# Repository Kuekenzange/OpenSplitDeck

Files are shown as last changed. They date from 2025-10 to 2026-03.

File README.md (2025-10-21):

# OpenSplitDeck (v0.2)

A custom modular wireless controller inspired by the Steam Deck and Steam Controller. Features trackpads, detachable halves, and full HID support. Built from scratch using nRF52840 microcontrollers and the Enhanced ShockBurst protocol. [Video](https://youtu.be/ycMgIToLav8?si=cVztny4IiIS_V4oI) 

Join the [Discord!](https://discord.gg/ZtV34Hwx7y)

> **Note**  
> This project is in an early development stage — v0.2. Expect breaking changes, bugs, and frequent updates.

---

## 🚀 Project Goals

- 🎮 Emulate a Steam Deck-like controller with modular, wireless halves
- 🖱️ Support mouse, keyboard, and gamepad HID modes
- 🧲 Custom-built trackpads using the Azoteq IQS7211E sensor
- 🔋 Magnetic pogo-pin charging and attachment system
- 🛠️ Fully open-source hardware and firmware

---

## 😎 Current Status

- 🎮 Emulates a DS4 Controller - This lets us use steam input for the trackpads. Ideally I want it to show up as a steamdeck controller but that is seeming like a much harder task than I thought.
- 🖱️ Support mouse, keyboard, and gamepad HID modes. - Kinda. Mouse and keyboard are properly setup in the HID desccriptors, I just have not implpemented them yet.
- 🧲 Custom-built trackpads using the Azoteq IQS7211E sensor - Yes.
- 🔋 Magnetic pogo-pin charging and attachment system. - Yes but they only support charging. I would like to find a way to make the 2 halves of the controller communicate with each other.
- 🛠️ Fully open-source hardware and firmware - 😎

Controller is still definetly in the early phases. However it does function and work as expected. There is still a lot to improve, optimize and other features to add. Stay tuned for the progression of this project and feel free to build one yourself! Let me know if my instructions are bad.

---

## ✅ v0.2 Development Checklist

### Hardware
- [x] Left and right controller halves (nRF52840)
- [x] USB dongle (nRF52840)
- [x] Custom trackpad PCBs (IQS7211E)
- [ ] 3D printable version of the Shell
- [x] Controller PCBs(left + right)
- [ ] Joystick PCBs(to drive down cost)
- [ ] gp2040ce + nrf dongle

### Firmware
- [x] ESB-based wireless communication
- [x] Mouse + Gamepad + Keyboard HID reports
- [x] Input parsing for trackpads and buttons
- [x] Haptics
- [ ] Rumble support
- [x] Gyro Support
- [ ] Calibration routines + save to internal memory
- [ ] Configurable modes (gesture/tap/mouse/gamepad)
- [x] Steam Input compatibility or XInput compatibility(This is now done through DS4)
- [ ] Capacitive Joystick

### 3d Modeling
- [ ] 3d Printable Case(Started, its in the STEP file)
- [ ] 3d Printable Shoulder Button Structure(Experimental Version in STEP file)
- [ ] 3d Printable Trigger Insert
- [ ] Trigger Locks

### Other
- [ ] Improve documentation and diagrams
- [x] Add Screens
- [ ] Design a UI or config utility(either software or adding screens)
- [X] Firmware migration to Zephyr
- [X] Optimize latency and packet loss handling (could still be better)
- [ ] Reduces costs

---

## 📷 Media

Coming soon — demo images, build progress, and gameplay tests.

---

## 🛠️ Build Instructions
- Schematic and board files:

  [LeftPCB](https://oshwlab.com/fbrains69/opensteamdeck-buttonpcb)

  [RightPCB](https://oshwlab.com/fbrains69/opensteamdeck-rightpcb)

  [Trackpad](https://oshwlab.com/fbrains69/steamdeck-controller-trackpad-v1-2)

- Firmware flashing instructions

  _(Coming soon)_
  
- BOM and Tools

  [Current BOM - Living Sheet (Im Trying to find the best way to source everything still)](https://docs.google.com/spreadsheets/d/1LNsZTH84R0wy0S3vBu-m3nQxl8zSZT1IippI82DKSO4/edit?usp=sharing)

- [Video Build Guide](https://youtu.be/64-y5n9kIJc)

- Written Build Guide
  _(Coming soon)__

---

## 🤝 Contributing

Contributions are welcome! Feel free to fork the repo, open issues, or submit pull requests.

If you're not sure where to start, check out the [Checklist](#-v01-development-checklist) for open tasks.

---

## 📄 License

MIT License — see `LICENSE` file for details.

---

## 💬 Contact

For questions or suggestions, reach out via GitHub Issues or [YouTube](https://www.youtube.com/@TommyBee456).

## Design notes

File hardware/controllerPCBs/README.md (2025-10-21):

VERY IMPORTANT- If ordering PCBs make sure they are 1mm thick. PCB fabs with often default to 1.6mm

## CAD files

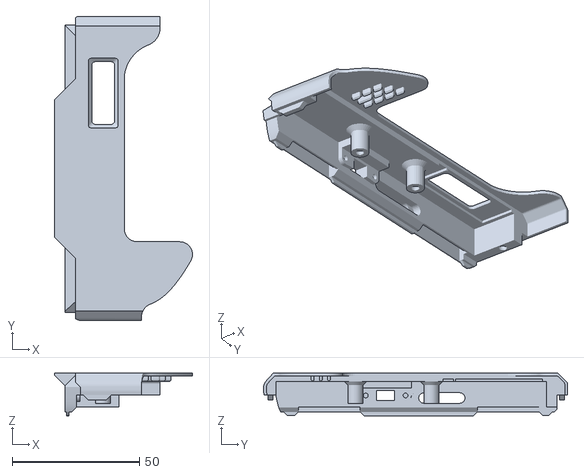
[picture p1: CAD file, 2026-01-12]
CAD/Connector Halves/Right Controller v3 Top.stl
54.2 x 119.4 x 16.7

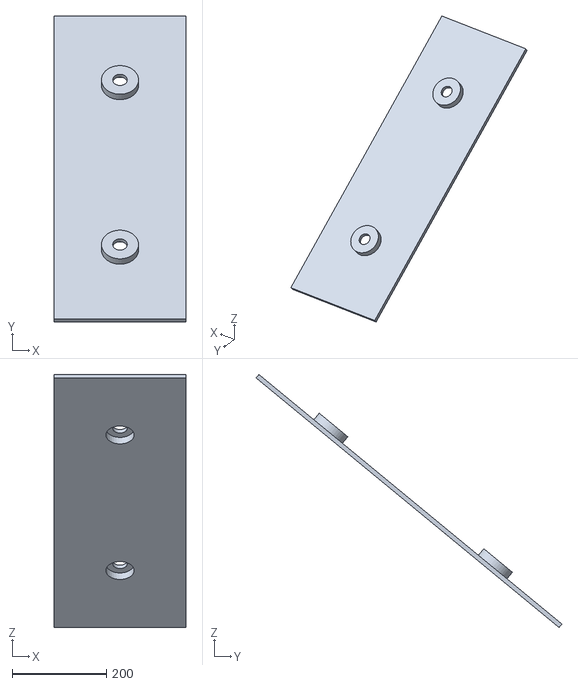
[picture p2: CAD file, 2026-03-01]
CAD/Dock+Dongle/HollowBottomLid.stl
279.4 x 649.8 x 537.5

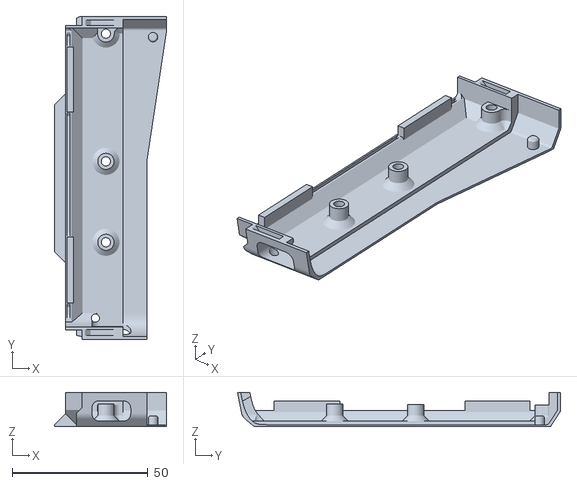
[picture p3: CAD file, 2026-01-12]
CAD/Connector Halves/Right Controller v3 Bottom.stl
41.4 x 119.1 x 12.6

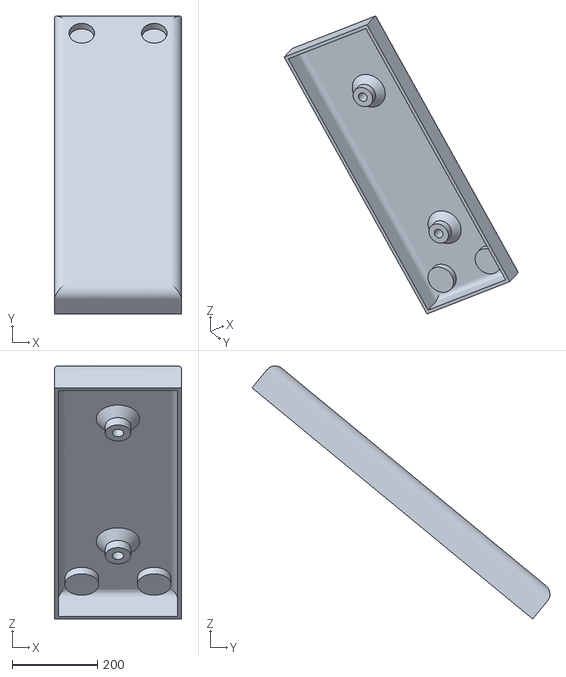
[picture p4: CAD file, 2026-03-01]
CAD/Dock+Dongle/HollowBottom.stl
298.4 x 698.9 x 593.5

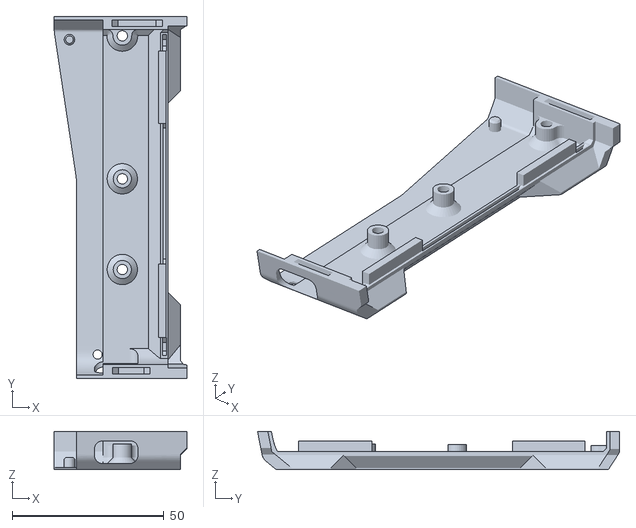
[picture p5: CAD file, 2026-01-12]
CAD/Connector Halves/Left Controller v3 Bottom.stl
43.6 x 119.1 x 12.6

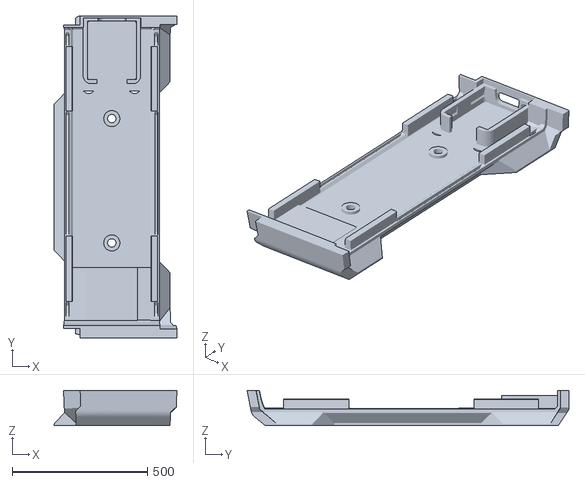
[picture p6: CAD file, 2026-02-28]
CAD/Dock+Dongle/DockBottom.stl
455.0 x 1190.9 x 130.7

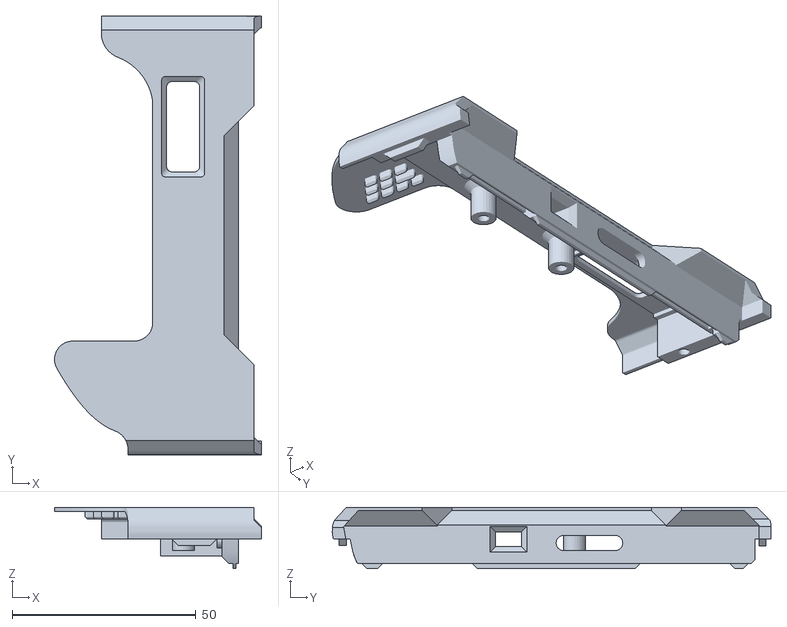
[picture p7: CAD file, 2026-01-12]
CAD/Connector Halves/Left Controller v3 Top.stl
56.4 x 119.4 x 16.7

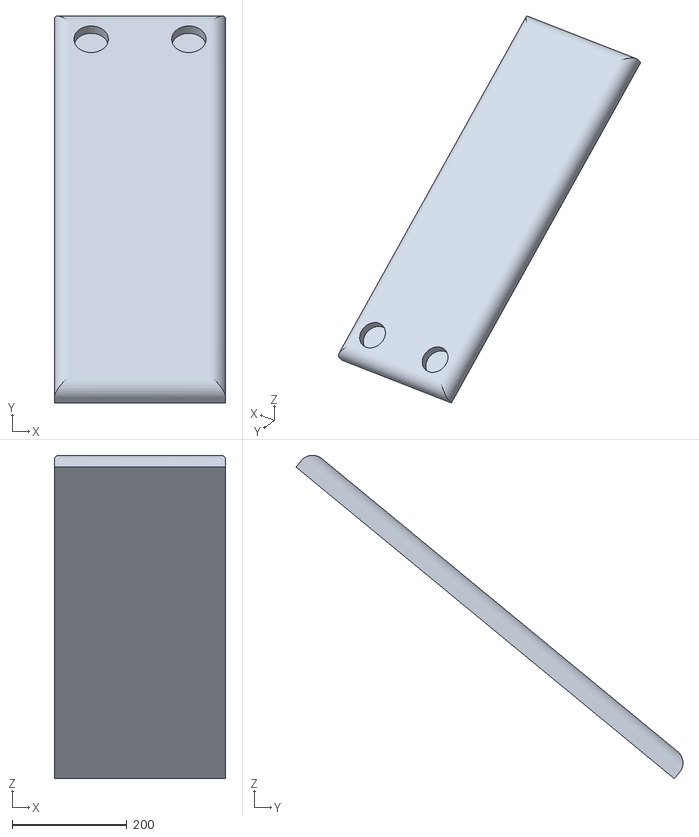
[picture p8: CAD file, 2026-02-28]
CAD/Dock+Dongle/Base.stl
298.4 x 673.5 x 562.7

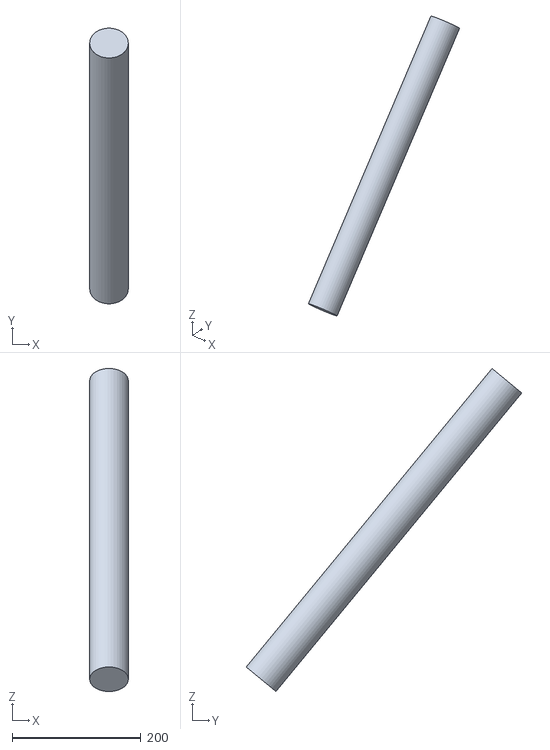
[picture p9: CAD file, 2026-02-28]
CAD/Dock+Dongle/Pillar.stl
60.0 x 427.6 x 501.2

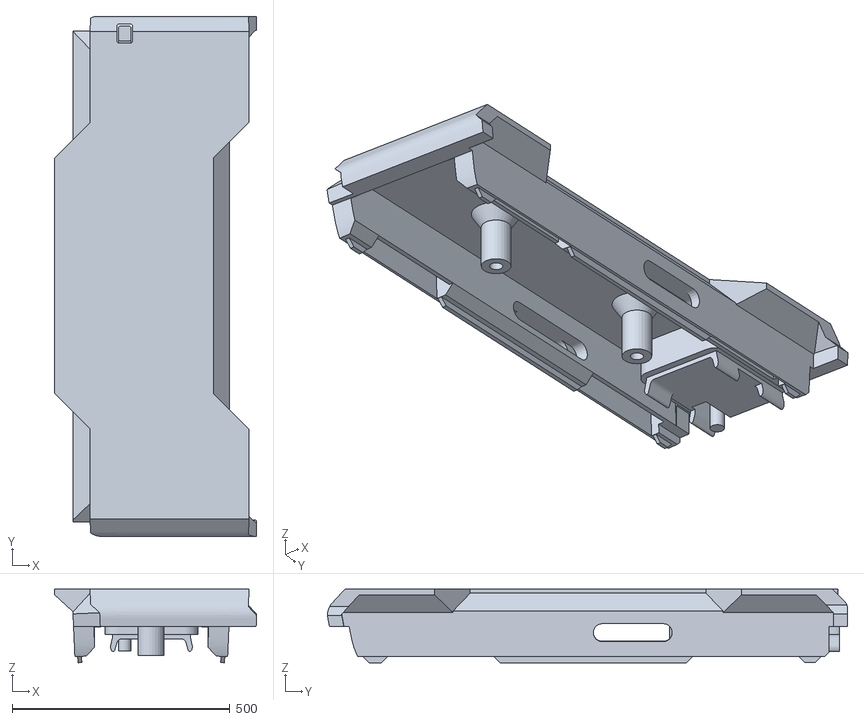
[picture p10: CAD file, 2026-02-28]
CAD/Dock+Dongle/DockTop.stl
465.5 x 1195.4 x 169.2

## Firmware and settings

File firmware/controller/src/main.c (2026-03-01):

  /*
 * Dual Controller System - Zephyr ESB Implementation
 *
 * This code runs on a Seeed Xiao BLE nRF52840 Sense Plus
 * It can be configured as LEFT or RIGHT controller half
 * Each half has a unique ID and only responds to its specific ping
 *
 * Configuration: Set CONTROLLER_ID below
 * - 0 = RIGHT controller (responds to ping value 0)
 * - 1 = LEFT controller (responds to ping value 1)
 */

// ========================
// CONTROLLER CONFIGURATION
// ========================
#define CONTROLLER_ID 0 // Change to 0 for RIGHT controller, 1 for LEFT controller


// FREEZE DEBUGGING - Temporarily disable components to isolate freezing source
#define FREEZE_DEBUG_DISABLE_ADC 0 // Set to 1 to disable ADC reads
#define FREEZE_DEBUG_DISABLE_IMU 0 // Set to 1 to disable IMU reads

#include <zephyr/kernel.h>
#include <zephyr/device.h>
#include <zephyr/drivers/gpio.h>
#include <zephyr/drivers/i2c.h>
#include <zephyr/pm/device.h>
#include <zephyr/drivers/sensor.h>
#include <zephyr/drivers/adc.h>
#include <zephyr/drivers/clock_control.h>
#include <zephyr/drivers/clock_control/nrf_clock_control.h>
#include <hal/nrf_saadc.h>
#include <nrfx_saadc.h>
#include <zephyr/pm/pm.h>
#include <zephyr/pm/state.h>
#include <zephyr/logging/log.h>
#if defined(CONFIG_ADC_NRFX_SAADC)
#include <nrfx_saadc.h>
#endif
#include <math.h>
#include <esb.h>
#include "IQS7211E.h"
#include "controller_storage.h"
#include "drv2605.h"
#include "display.h"
#include "haptic_driver.h"
#include "imu_driver.h"
#include "button_driver.h"
#include "analog_driver.h"
#include "esb_comm_driver.h"
#include "power_mgmt_driver.h"
#include "IQS7211E_init.h"
// #include "trackpad_driver.h"

LOG_MODULE_REGISTER(controller, LOG_LEVEL_INF);

// LED for status indication
static const struct gpio_dt_spec led0 = GPIO_DT_SPEC_GET(DT_ALIAS(led0), gpios);

// Display State Varibles
static display_screen_type_t current_display_screen = DISPLAY_SCREEN_STATUS;
static display_analog_data_t display_analog_data = {0};
static uint8_t calibration_phase = 0;      // 0=centering, 1=movement
static uint8_t calibration_progress = 0;   // 0-100%
// REMOVED display_mutex - was causing priority inversion and 100-160ms thread delays
// Main thread (200Hz) calling display_set_screen competed with display thread (20Hz)

// I2C bus protection - REMOVED due to causing thread delays
// static K_MUTEX_DEFINE(i2c1_mutex);

// Thread health monitoring
static uint32_t trackpad_thread_heartbeat = 0;
static uint32_t display_thread_heartbeat = 0;

// Controller button GPIO definitions (used by button driver)
static const struct gpio_dt_spec stick_click = {
    .port = DEVICE_DT_GET(DT_NODELABEL(gpio0)),
    .pin = 29,
    .dt_flags = GPIO_ACTIVE_LOW};

static const struct gpio_dt_spec bumper = {
    .port = DEVICE_DT_GET(DT_NODELABEL(gpio1)),
    .pin = 11,
    .dt_flags = GPIO_ACTIVE_LOW};

static const struct gpio_dt_spec start = {
    .port = DEVICE_DT_GET(DT_NODELABEL(gpio1)),
    .pin = 12,
    .dt_flags = GPIO_ACTIVE_LOW};

static const struct gpio_dt_spec button_p4 = {
    .port = DEVICE_DT_GET(DT_NODELABEL(gpio0)),
    .pin = 15,
    .dt_flags = GPIO_ACTIVE_LOW};

static const struct gpio_dt_spec button_p5 = {
    .port = DEVICE_DT_GET(DT_NODELABEL(gpio0)),
    .pin = 19,
    .dt_flags = GPIO_ACTIVE_LOW};

static const struct gpio_dt_spec mode_button = {
    .port = DEVICE_DT_GET(DT_NODELABEL(gpio1)),
    .pin = 1,
    .dt_flags = GPIO_ACTIVE_LOW};

static const struct gpio_dt_spec dpad_down = {
    .port = DEVICE_DT_GET(DT_NODELABEL(gpio1)),
    .pin = 13,
    .dt_flags = GPIO_ACTIVE_LOW};

static const struct gpio_dt_spec dpad_left = {
    .port = DEVICE_DT_GET(DT_NODELABEL(gpio1)),
    .pin = 14,
    .dt_flags = GPIO_ACTIVE_LOW};

static const struct gpio_dt_spec dpad_right = {
    .port = DEVICE_DT_GET(DT_NODELABEL(gpio1)),
    .pin = 15,
    .dt_flags = GPIO_ACTIVE_LOW};

static const struct gpio_dt_spec dpad_up = {
    .port = DEVICE_DT_GET(DT_NODELABEL(gpio1)),
    .pin = 3,
    .dt_flags = GPIO_ACTIVE_LOW};

static const struct gpio_dt_spec pad_click = {
    .port = DEVICE_DT_GET(DT_NODELABEL(gpio1)),
    .pin = 7,
    .dt_flags = GPIO_ACTIVE_LOW};

// DRV2605 Haptic motor control pins (NFC pins - requires NFC disabled)
static const struct gpio_dt_spec haptic_trigger = {
    .port = DEVICE_DT_GET(DT_NODELABEL(gpio0)),
    .pin = 9, // P0.09 (NFC1) - External trigger pin
    .dt_flags = GPIO_ACTIVE_HIGH};

static const struct gpio_dt_spec haptic_enable_pin = {
    .port = DEVICE_DT_GET(DT_NODELABEL(gpio0)),
    .pin = 10, // P0.10 (NFC2) - Enable pin
    .dt_flags = GPIO_ACTIVE_HIGH};

// Battery voltage divider enable pin (XIAO nRF52840)
static const struct gpio_dt_spec vbat_enable = {
    .port = DEVICE_DT_GET(DT_NODELABEL(gpio0)),
    .pin = 14,                    // P0.14 - Battery voltage divider enable (LOW=enabled, HIGH=disabled)
    .dt_flags = GPIO_ACTIVE_LOW}; // Active low means setting to 0 enables the divider

// Trackpad RDY pin for interrupt-based reading
static const struct gpio_dt_spec trackpad_rdy = {
    .port = DEVICE_DT_GET(DT_NODELABEL(gpio1)),
    .pin = 5, // P1.05 - RDY pin from trackpad
        .dt_flags = GPIO_ACTIVE_LOW};

// Removed unused trackpad_ready GPIO spec

// I2C for peripherals
static const struct device *i2c_dev;

// IMU sensor - Now using imu_driver library

// ADC for analog inputs - Now using analog_driver library
static const struct device *adc_dev;

// Forward declarations for power management functions
void shutdown_all_peripherals(void);
void wakeup_all_peripherals(void);
void power_factory_reset_handler(void);

// Global flag to track if we need safe shutdown
// Sleep mode state

// Storage for configuration data
static controller_calibration_t controller_calibration;
static controller_bindings_t controller_bindings;
static controller_preferences_t controller_preferences;

// ESB payload structures - now using ESB communication driver
// Controller state
static esb_controller_data_t controller_data = {0};

// ACK rumble -> DRV2605 effect switching state (shared motor with trackpad clicks)
static const drv2605_effect_t HAPTIC_CLICK_EFFECT = DRV2605_EFFECT_SHARP_TICK_2;
static const drv2605_effect_t HAPTIC_RUMBLE_EFFECT = DRV2605_EFFECT_STRONG_BUZZ_100;
static bool ack_rumble_mode_active = false;
static uint32_t ack_rumble_last_nonzero_ms = 0;
static uint32_t ack_rumble_last_pulse_ms = 0;
static const uint32_t ACK_RUMBLE_RESTORE_DELAY_MS = 180;
static volatile bool trackpad_init_in_progress = false;
static volatile bool trackpad_init_complete = false;

// Function declarations
void buttons_init(void);                      // Initialize button driver
void adc_init(void);                          // Initialize analog driver
void esb_comm_init(void);                     // Initialize ESB communication driver
void read_button_inputs(void);                // Read buttons using driver
void read_analog_inputs(void);                // Read analog using driver
void print_analog_values(void);               // Debug: print all analog values
void calibrate_analog_inputs(void);           // Calibrate analog using driver
void read_imu_inputs(void);                   // Read IMU using driver
esb_comm_status_t send_controller_data(void); // Send data using ESB driver
void power_mgmt_init(void);                   // Initialize power management driver
void ui_init(void);                           // UI placeholder functions
void ui_create_main_screen(void);
void ui_create_menu_screen(void);
void ui_create_calibration_screen(void);
void ui_update_data(void);
void ui_handle_input(void);
static void process_ack_rumble_haptics(uint8_t left_rumble, uint8_t right_rumble);
static bool trackpad_wait_rdy_low(uint32_t timeout_ms);

static void process_ack_rumble_haptics(uint8_t left_rumble, uint8_t right_rumble)
{
        if (!haptic_is_available())
        {
                return;
        }

        // Do not vibrate while the trackpad is still initializing
        if (trackpad_init_in_progress || !trackpad_init_complete)
        {
                return;
        }

        uint8_t rumble_level = (left_rumble > right_rumble) ? left_rumble : right_rumble;
        uint32_t now = k_uptime_get_32();

        if (rumble_level > 0)
        {
                ack_rumble_last_nonzero_ms = now;

                // Temporarily switch external-trigger waveform to rumble effect
                if (!ack_rumble_mode_active)
                {
                        if (haptic_set_trigger_effect(HAPTIC_RUMBLE_EFFECT) == 0)
                        {
                                ack_rumble_mode_active = true;
                                (void)haptic_trigger_pulse();
                                ack_rumble_last_pulse_ms = now;
                                LOG_INF("ACK rumble active - switched haptic effect to buzz");
                        }
                        else
                        {
                                LOG_WRN("Failed to switch to rumble effect");
                                return;
                        }
                }

                // Tuned pulse cadence bands for smoother perceived intensity
                uint32_t pulse_interval_ms = 120;
                if (rumble_level >= 12)
                {
                        pulse_interval_ms = 32;
                }
                else if (rumble_level >= 8)
                {
                        pulse_interval_ms = 48;
                }
                else if (rumble_level >= 4)
                {
                        pulse_interval_ms = 72;
                }
                else
                {
                        pulse_interval_ms = 108;
                }

                if ((now - ack_rumble_last_pulse_ms) >= pulse_interval_ms)
                {
                        (void)haptic_trigger_pulse();
                        ack_rumble_last_pulse_ms = now;
                }
        }
        else if (ack_rumble_mode_active)
        {
                // Keep rumble effect briefly to avoid rapid mode thrash from packet jitter
                if ((now - ack_rumble_last_nonzero_ms) >= ACK_RUMBLE_RESTORE_DELAY_MS)
                {
                        if (haptic_set_trigger_effect(HAPTIC_CLICK_EFFECT) == 0)
                        {
                                ack_rumble_mode_active = false;
                                LOG_INF("ACK rumble inactive - restored click effect");
                        }
                        else
                        {
                                LOG_WRN("Failed to restore click effect after rumble");
                        }
                }
        }
}

// Initialize ESB communication using ESB driver library
void esb_comm_init(void)
{
        LOG_INF("Initializing ESB communication using driver library...");

        // Configure ESB communication
        // Configure timing with controller-specific offset to prevent collisions
        uint32_t base_interval = 5;   // 5ms base for RIGHT controller
        uint32_t retry_interval = 10; // 10ms retry for RIGHT controller

        // LEFT controller gets +2ms offset to stagger transmissions
        if (CONTROLLER_ID == 1)
        {                            // LEFT controller
                base_interval += 2;  // 7ms instead of 5ms
                retry_interval += 2; // 12ms instead of 10ms
        }

        esb_comm_config_t esb_config = {
            .controller_id = CONTROLLER_ID,
            .base_tx_interval_ms = base_interval,
            .retry_interval_ms = retry_interval,
            .rf_channel = 50,   // RF channel 50 (2450 MHz) - MUST match dongle
            .status_led = &led0 // Use LED0 for status indication
        };

        LOG_INF("Controller %d ESB timing: base=%dms, retry=%dms (offset for collision avoidance)",
                CONTROLLER_ID, base_interval, retry_interval);
        LOG_INF("Note: Actual timing controlled by dongle ACK payload when available");

        esb_comm_status_t status = esb_comm_driver_init(&esb_config);
        if (status != ESB_COMM_STATUS_OK)
        {
                LOG_ERR("ESB communication driver initialization failed: %d", status);
                return;
        }

        // Enable ACK payload based timing
        status = esb_comm_enable_ack_timing(true);
        if (status == ESB_COMM_STATUS_OK)
        {
                LOG_INF("ACK payload timing enabled");
        }
        else
        {
                LOG_WRN("Failed to enable ACK payload timing: %d", status);
        }

        LOG_INF("ESB communication driver initialized successfully");
}
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
int main(void)
{
        int ret;

        LOG_INF("Zephyr ESB Controller Starting...");

        // Initialize LED
        if (!gpio_is_ready_dt(&led0))
        {
                LOG_ERR("LED device not ready");
                return -ENODEV;
        }
        gpio_pin_configure_dt(&led0, GPIO_OUTPUT_INACTIVE);

        // Initialize battery voltage divider (XIAO nRF52840 safe approach)
        if (!gpio_is_ready_dt(&vbat_enable))
        {
                LOG_ERR("VBAT enable GPIO not ready");
                return -ENODEV;
        }

        // Try different GPIO configuration approaches for P0.14
        LOG_INF("Attempting to configure P0.14 as current sink for voltage divider control...");

        // Method 1: Open-drain output (proper current sink)
        ret = gpio_pin_configure_dt(&vbat_enable, GPIO_OUTPUT_INACTIVE | GPIO_OPEN_DRAIN);
        if (ret != 0)
        {
                LOG_ERR("Failed to configure P0.14 as open-drain: %d", ret);
        }

        ret = gpio_pin_set_dt(&vbat_enable, 0); // Active LOW for current sink
        if (ret != 0)
        {
                LOG_ERR("Failed to set P0.14 to 0: %d", ret);
        }

        // Method 2: If open-drain not supported, try standard output with pull-down
        if (ret != 0)
        {
                ret = gpio_pin_configure_dt(&vbat_enable, GPIO_OUTPUT | GPIO_PULL_DOWN);
                if (ret == 0)
                {
                        ret = gpio_pin_set_dt(&vbat_enable, 0);
                        int pin_state = gpio_pin_get_dt(&vbat_enable);
                        LOG_INF("Method 2 (output+pulldown) result: set_result=%d, pin_state=%d", ret, pin_state);
                }
        }

        // Method 3: Raw GPIO register access for open-drain if needed
        if (ret != 0)
        {
                const struct device *gpio_dev = DEVICE_DT_GET(DT_NODELABEL(gpio0));
                if (device_is_ready(gpio_dev))
                {
                        ret = gpio_pin_configure(gpio_dev, 14, GPIO_OUTPUT | GPIO_OPEN_DRAIN);
                        if (ret == 0)
                        {
                                ret = gpio_pin_set_raw(gpio_dev, 14, 0);
                                int raw_state = gpio_pin_get_raw(gpio_dev, 14);
                                LOG_INF("Method 3 (raw open-drain) result: set_result=%d, raw_pin_state=%d", ret, raw_state);
                        }
                }
        }

        // Final verification
        int final_pin_state = gpio_pin_get_dt(&vbat_enable);
        LOG_INF("Final P0.14 state: %d (configured as current sink)", final_pin_state);

        if (final_pin_state != 0)
        {
                LOG_WRN("P0.14 not sinking current properly - voltage divider may not work");
        }
        else
        {
                LOG_INF("P0.14 configured as current sink - should enable voltage divider");
        }

        // Initialize controller buttons
        buttons_init();

        // Initialize ADC for analog inputs
        adc_init();

        // Initialize ESB communication
        esb_comm_init();

        // Initialize I2C for trackpad (when connected) - MOVED TO LATER
        i2c_dev = DEVICE_DT_GET(DT_NODELABEL(i2c1));

        // Get I2C0 for IMU
        const struct device *imu_i2c_dev = DEVICE_DT_GET(DT_NODELABEL(i2c0));
        if (!device_is_ready(imu_i2c_dev))
        {
                LOG_ERR("I2C0 device not ready for IMU");
        }
        else
        {
                LOG_INF("I2C0 ready for IMU");
        }

        // Initialize SSD1306 display using display library
        LOG_INF("About to call display_library_init(CONTROLLER_ID=%d)", CONTROLLER_ID);
        ret = display_library_init(CONTROLLER_ID);
        LOG_INF("display_library_init returned: %d, status now: %d", ret, display_get_status());
        if (ret != 0)
        {
                LOG_WRN("Display initialization failed: %d", ret);
        }
        else
        {
                LOG_INF("Display library initialized successfully");
        }

        // Initialize haptic motor driver using haptic_driver library
        // Initialize haptic motor driver using haptic_driver library
        ret = haptic_driver_init(i2c_dev, &haptic_trigger, &haptic_enable_pin);
        if (ret != 0)
        {
                LOG_WRN("Haptic driver initialization failed: %d", ret);
        }
        else
        {
                // Small delay for DRV2605 to fully initialize
                k_sleep(K_MSEC(100));

                // Perform LRA auto-calibration BEFORE setting up external trigger
                LOG_INF("Starting LRA haptic auto-calibration...");
                ret = haptic_perform_lra_calibration();
                if (ret != 0)
                {
                        LOG_WRN("Haptic auto-calibration failed: %d", ret);
                }

                // Setup external trigger mode with LRA-optimized effect (after calibration)
                ret = haptic_setup_external_trigger(DRV2605_EFFECT_SHARP_TICK_2);
                if (ret != 0)
                {
                        LOG_WRN("Haptic external trigger setup failed: %d", ret);
                }
        }

        // Initialize power management (with combos disabled for now)
        power_mgmt_config_t power_config = {
            .wake_button1 = &mode_button,         // Use mode button as wake button
            .wake_button2 = NULL,                 // Use existing button as wake button 2
            .status_led = &led0,                  // Use system LED for status
            .shutdown_combo_hold_ms = 5000,       // 30 second hold for shutdown (very long to prevent accidental)
            .factory_reset_combo_hold_ms = 50000, // 50 second hold for factory reset (very long)
            .auto_sleep_enabled = false,          // Disable auto-sleep for now
            .auto_sleep_timeout_ms = 300000       // 5 minutes auto-sleep (when enabled)
        };

        power_mgmt_status_t pm_status = power_mgmt_driver_init(&power_config);
        if (pm_status != POWER_MGMT_STATUS_OK)
        {
                LOG_WRN("Power management initialization failed: %d", pm_status);
        }

        // Register power management callbacks for peripheral control
        power_mgmt_register_shutdown_callback(shutdown_all_peripherals);
        power_mgmt_register_wakeup_callback(wakeup_all_peripherals);

        // Disable button combos to prevent accidental system restart
        // These will only be enabled when intentionally entering sleep mode
        power_mgmt_enable_combo(BUTTON_COMBO_SHUTDOWN, false);
        power_mgmt_enable_combo(BUTTON_COMBO_FACTORY_RESET, false);
        LOG_INF("Power management button combos disabled for normal operation");

        // Initialize storage subsystem
        ret = controller_storage_init();
        if (ret != 0)
        {
                LOG_ERR("Failed to initialize storage: %d", ret);
                // Continue without storage - use defaults
        }
        else
        {
                // Load configuration from flash
                controller_storage_load_calibration(&controller_calibration);
                controller_storage_load_bindings(&controller_bindings);
                controller_storage_load_preferences(&controller_preferences);
                
                // Debug: Show what was loaded from flash
                LOG_INF("=== LOADED CALIBRATION FROM FLASH ===");
                LOG_INF("Stick X: center=%d, min=%d, max=%d, deadzone=%d",
                        controller_calibration.stick_center_x,
                        controller_calibration.stick_min_x,
                        controller_calibration.stick_max_x,
                        controller_calibration.stick_deadzone);
                LOG_INF("Stick Y: center=%d, min=%d, max=%d",
                        controller_calibration.stick_center_y,
                        controller_calibration.stick_min_y,
                        controller_calibration.stick_max_y);
                LOG_INF("Trigger: min=%d, max=%d",
                        controller_calibration.trigger_min,
                        controller_calibration.trigger_max);
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

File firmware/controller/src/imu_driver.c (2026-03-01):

/**
 * @file imu_driver.c
 * @brief IMU sensor driver implementation for LSM6DS3TR-C
 */

#include "imu_driver.h"

LOG_MODULE_REGISTER(imu_driver, LOG_LEVEL_ERR);

#define IMU_GRAVITY_MPS2 9.81
#define IMU_STILL_ACCEL_TOLERANCE_MPS2 0.8
#define IMU_STILL_GYRO_THRESHOLD_RAD_S 0.08
#define IMU_DRIFT_BIAS_ALPHA 0.01
#define IMU_GYRO_RADIAL_DEADBAND_RAD_S 0.01
#define IMU_GYRO_OUTPUT_DEADBAND_COUNTS 35

typedef struct {
    double gyro_bias_x;
    double gyro_bias_y;
    double gyro_bias_z;
    uint32_t still_sample_count;
} imu_drift_comp_t;

static imu_drift_comp_t imu_drift_comp = {0};

// Global IMU context
static imu_context_t imu_ctx = {
    .sensor_dev = NULL,
    .i2c_dev = NULL,
    .status = IMU_STATUS_NOT_READY,
    .config = {0},
    .raw_data = {0},
    .filtered_data = {0},
    .calibration = {0},
    .read_count = 0,
    .error_count = 0
};

// Default configuration
static const imu_config_t DEFAULT_CONFIG = {
    .accel_odr = 104,               // 104 Hz
    .gyro_odr = 104,                // 104 Hz  
    .filter_alpha = 0.4f,           // Moderate filtering
    .auto_calibrate = false,        // Manual calibration
    .accel_scale_factor = 800.0f,   // Scale to controller range
    .gyro_scale_factor = 1200.0f    // Scale to controller range
};

static void imu_update_runtime_gyro_bias(bool is_still, double gx, double gy, double gz)
{
    if (is_still) {
        if (imu_drift_comp.still_sample_count < UINT32_MAX) {
            imu_drift_comp.still_sample_count++;
        }

        // Require short still period before adapting bias
        if (imu_drift_comp.still_sample_count >= 20) {
            imu_drift_comp.gyro_bias_x = (1.0 - IMU_DRIFT_BIAS_ALPHA) * imu_drift_comp.gyro_bias_x + IMU_DRIFT_BIAS_ALPHA * gx;
            imu_drift_comp.gyro_bias_y = (1.0 - IMU_DRIFT_BIAS_ALPHA) * imu_drift_comp.gyro_bias_y + IMU_DRIFT_BIAS_ALPHA * gy;
            imu_drift_comp.gyro_bias_z = (1.0 - IMU_DRIFT_BIAS_ALPHA) * imu_drift_comp.gyro_bias_z + IMU_DRIFT_BIAS_ALPHA * gz;
        }
    } else {
        imu_drift_comp.still_sample_count = 0;
    }
}

/**
 * @brief Initialize the IMU driver system
 */
int imu_driver_init(const struct device *sensor_dev, 
                   const struct device *i2c_dev,
                   const imu_config_t *config)
{
    LOG_INF("=== IMU DRIVER INITIALIZATION ===");
    
    // Clear the context
    memset(&imu_ctx, 0, sizeof(imu_ctx));
    memset(&imu_drift_comp, 0, sizeof(imu_drift_comp));
    imu_ctx.status = IMU_STATUS_NOT_READY;
    
    // Store device references
    imu_ctx.sensor_dev = sensor_dev;
    imu_ctx.i2c_dev = i2c_dev;
    
    // Use provided config or defaults
    if (config) {
        imu_ctx.config = *config;
    } else {
        imu_ctx.config = DEFAULT_CONFIG;
    }
    
    // Check if sensor device is available
    if (!sensor_dev) {
        LOG_ERR("IMU sensor device not provided");
        imu_ctx.status = IMU_STATUS_ERROR;
        return -ENODEV;
    }
    
    // Check if sensor device is ready (be more permissive like the original code)
    if (!device_is_ready(sensor_dev)) {
        LOG_WRN("IMU sensor device not ready - attempting initialization anyway");
        // Don't return error immediately, try to proceed like the original code
    } else {
        LOG_INF("LSM6DS3TR-C IMU sensor device ready");
    }
    
    // Configure accelerometer output data rate
    struct sensor_value odr_val = {
        .val1 = imu_ctx.config.accel_odr,
        .val2 = 0
    };
    
    int ret = sensor_attr_set(sensor_dev, SENSOR_CHAN_ACCEL_XYZ, 
                             SENSOR_ATTR_SAMPLING_FREQUENCY, &odr_val);
    if (ret == 0) {
        LOG_INF("Accelerometer ODR set to %d Hz", imu_ctx.config.accel_odr);
    } else {
        LOG_WRN("Failed to set accelerometer ODR: %d", ret);
    }
    
    // Configure gyroscope output data rate
    ret = sensor_attr_set(sensor_dev, SENSOR_CHAN_GYRO_XYZ, 
                         SENSOR_ATTR_SAMPLING_FREQUENCY, &odr_val);
    if (ret == 0) {
        LOG_INF("Gyroscope ODR set to %d Hz", imu_ctx.config.gyro_odr);
    } else {
        LOG_WRN("Failed to set gyroscope ODR: %d", ret);
    }
    
    // Initialize calibration to neutral values
    imu_reset_calibration();
    
    // Test initial sensor read (be more permissive like original code)
    ret = imu_read_raw_data(NULL);
    if (ret == 0) {
        LOG_INF("Initial IMU sensor read successful");
        imu_ctx.status = IMU_STATUS_READY;
    } else {
        LOG_WRN("Initial IMU sensor read failed: %d", ret);
        LOG_INF("IMU may not be present on this board variant");
        imu_ctx.status = IMU_STATUS_NOT_DETECTED;
        return -ENODEV;  // Return error like original code would
    }
    
    LOG_INF("=== IMU DRIVER INIT COMPLETE ===");
    return 0;
}

/**
 * @brief Get the current IMU driver status
 */
imu_status_t imu_get_status(void)
{
    return imu_ctx.status;
}

/**
 * @brief Check if IMU driver is available and ready
 */
bool imu_is_available(void)
{
    return (imu_ctx.status == IMU_STATUS_READY);
}
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

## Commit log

2025-10-21 Add note on PCB thickness requirement
2025-12-09 Modified top connector pieces to make screen a bit easier to solder in
    screen now sits a bit deeper but is much easier to solder
    [Left Controller v3 Top.stl, Right Controller v3 Top.stl]
2026-01-12 updated connector halves
    slightly tighter tolerances
    [Left Controller v3 Bottom.stl, Left Controller v3 Top.stl, Right Controller v3 Bottom.stl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]
2026-02-05 Added an ordering guide for the custom PCBs from JLCPCB
2026-02-28 dock with integrated dongle
    [Base.stl, DockBottom.stl, DockTop.stl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]
2026-03-01 Rewrote trackpad init function to be more reliable
    had issues when on lower than 50% battery that the trackpad would fail to init on some controllers. This should fix it. Also trackpad init is much faster, should work once screen has a picture.
    [IQS7211E.c, controller_esb.c, main.c]
